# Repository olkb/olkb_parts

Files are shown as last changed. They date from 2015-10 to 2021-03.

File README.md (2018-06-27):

# OLKB Design Files

These are the source files for the hardware made (currently and previously) by [OLKB](https://olkb.com).

> These works are licensed under the Creative Commons Attribution-ShareAlike 4.0 International License. To view a copy of this license, visit http://creativecommons.org/licenses/by-sa/4.0/ or send a letter to Creative Commons, PO Box 1866, Mountain View, CA 94042, USA.

This means you can run Group Buys of these designs, as long as you credit where the design came from (this repo).

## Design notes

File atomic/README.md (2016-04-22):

# The Atomic Keyboard

## Tops

* TOPASK50: Short space
* TOPAUN50: Universal MX
* TOPJAS50: Semi-grid
* TOPJCK50: Semi-standard
* TOPKLN50: Full-grid
* TOPMAU50: Universal Matias
* TOPMLO50: Alt short space

## Middles

* MIDATM50: Middle piece with stabiliser and usb cut-out

## Bottoms

* BOTATM50-MSH: Milled bottom
* BOTATM50: Plate bottom

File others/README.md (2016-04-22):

# Other keyboard designs

* BOTNEU50: Neutrino bottom plate
* MIDMOL50: Neutrino middle piece
* TOPNEU50: Neutrino top plate
* TOPQUA50: Quark top plate

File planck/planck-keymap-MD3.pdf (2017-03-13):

### Main typing layers (Qwerty, Lower, Raise)

# Planck default keymap - QMK Firmware

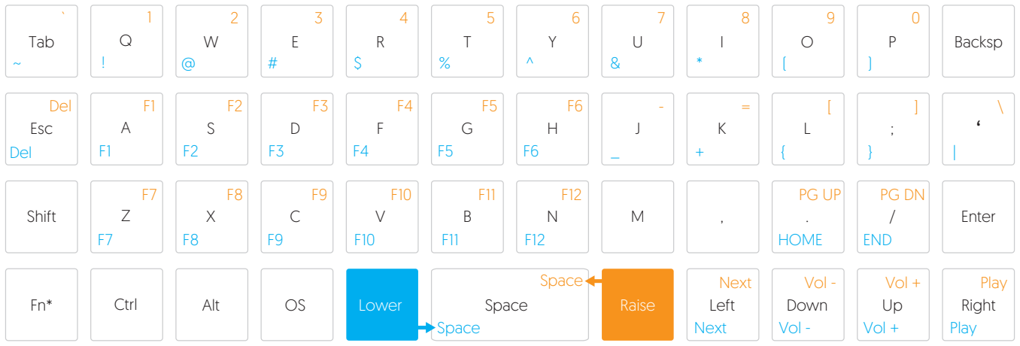
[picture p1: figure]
Tab; Backsp; Del; HOME; END; Next; Vol -; Vol +; Play; ‘ Esc; Shift; Enter; Ctrl; Alt; Lower; Space; Raise; Left; Down; Right

### Adjust layer (Lower + Raise together)

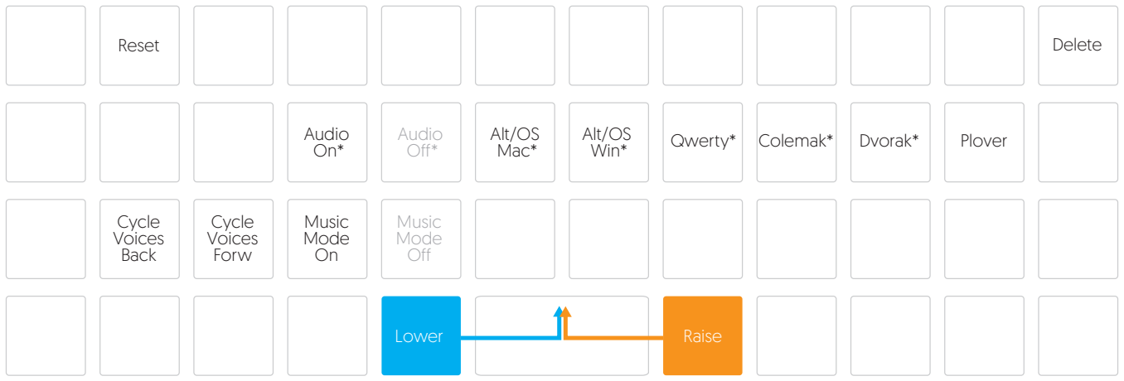
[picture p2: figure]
Reset; Music Mode On; Cycle Voices Forw; Cycle Voices Back; Audio On*; Alt/OS; Mac*; Qwerty* Colemak* Dvorak*; Plover; Delete; Alt/OS Win*; Audio Off*; Music Mode Off; Lower; Raise

* These options are persistant over keyboard power loss and stored in the EEPROM (you’ll only need to set them once)

* Fn presses shift and cycles through the backlight settings

For more information on the firmware, visit https://github.com/qmk/qmk_firmware. The default keymap evolves over time, and the one in the repo may be slightly different than what is shown here - for the Massdrop that started in March 2017, this is the keymap that came programmed onto the PCBs, and can be used as a typing reference.

Many keys on the Lower/Raise layers were left blank for customising, so consider adjusting things to your liking! Compiling instructions are on the repo’s wiki.

## OLKB.COM

keyboard store

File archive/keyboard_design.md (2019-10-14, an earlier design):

Terminology

FROM SWITCH CENTER (FSC)

When discussing the spacings around the edge of the plate, the terminology "from switch center" (FSC) will be used. In that sense, the MX switch cutouts themselves are 7mm FSC, or 14mm x 14mm. The standard plate designs for OLKB are all 12mm FSC - this means the plates come out 2.5mm from the edge of the keycaps. Some 9.5mm FSC plates/cases are also being planned.

GRID SPACING (GS)

The Planck, Atomic, and Matias boards use a 19mm grid spacing (GS), meaning there is 19mm between the switch centers for two normal, 1 unit keys - with this, 1u (unit) can be defined as 19mm. Other common boards (Cherry, etc) have a 19.05mm GS.

View All OLKB parts on github

PLANCK

The 12mm FSC plates are 233mm x 81mm in size and 1.54mm thick (16 gauge stainless steel), with 2.5mm (previously 3mm) diameter mounting holes in the following locations (distances from top left corner when looking down) (x, y):

(21.5mm, 21.5mm)

(211.5mm, 21.5mm)

(116.5mm, 40.5mm)

(21.5mm, 59.5mm)

(211.5mm, 59.5mm)

The PCB was designed to fit into the milled cases - the walls of which start at 8.9mm FSC, and are 3.1mm thick. The inside corner radius of the walls is 6.35mm - this makes the case cheaper to produce, and comes right to the edge of the keyswitches.

3D PRINT YOUR OWN PLANCK PARTS!

View all of the parts on github. (Atomic and other parts are available too)

Adam Forland has kindly proto-printed the Planck bottom using the plans I made for the Planck milled bottom. This 6-piece design turns out slightly better due to ABS's tendency to warp, and can be easily glued together.

The Planck bottom has 1.6mm diameter holes, which are ready to tap with a 2mm/M2 tap for the assembly kits I sell.

The Planck middle piece is designed for use with the regular bottom plate (and top plate), and shares the same side clearances as the bottom piece.

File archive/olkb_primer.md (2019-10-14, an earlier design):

Mechanical keyboards can be a little overwhelming when seeing all of the different options! This page will serve as a brief guide on what you might be buying from OLKB or other stores. Feel free to suggest additional links/info!

## Guides to check out

* [OLKB PCB assembly guide](http://olkb.com/help/guide)
* [Quantum firmware documentation (up-to-date)](https://docs.qmk.fm)
* [How to hand-wire a keyboard](http://deskthority.net/workshop-f7/brownfox-step-by-step-t6050.html)

## The term "ortholinear"

Ortholinear is a semi-made-up word that was originally coined (to my knowledge) by [TypeMatrix](http://www.typematrix.com/study/) as "ortho-linear" - this term got concatenated, became popular among the keyboard community, and eventually became the banner for a keyboard company!

It refers to keyboard layouts where the keys are aligned vertically and horizontally, compared to standard staggered keyboards. No studies have been done to test the ergonomics of ortholinear keyboards (versus a comparable staggered one), but the change can make it easier to design and visual custom keymaps, and may help relieve RSI symptoms.

## Construction

The keyboards sold on OLKB generally have a top and a bottom (and sometimes a middle) - the switches fit into holes in the top plate, and then are either hand-wired to a Teensy 2.0 (or other microcontroller) or a PCB. In practice, it's much easier to place the switches one-by-one into the plate *and* PCB than it is to place all switches into the plate, *then* the PCB.

10mm between the top and bottom plates is usually enough room to fit all of the necessary components for a PCB or hand-wired build. Additional M2 brass spacer sizes [can be found on Amazon](http://www.amazon.com/s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).

## Switch Types

There are a lot of different types of modern switches, but they can be separately into two categories that are available for these/custom keyboards:

* MX-compatible switches
  * Cherry MX
  * Gateron
  * Kailh
  * Greetech
* Matias-compatible switches
  * Matias
  * ALPS XM

Each has variations that will affect the feeling/sound of the switch, and are usually denoted by colors. [More information on the various types can be found here](https://www.reddit.com/r/MechanicalKeyboards/wiki/switch_guides).

## OLKB Keyboards

I'm always thinking about new keyboards to make, but these are the OLKB keyboards that have been announced/are for sale currently:

* [Planck](/planck) - a 40% (4u x 12u) keyboard
* [Preonic](/preonic) - a 50% (5u x 12u) keyboard

## Firmware

The PCBs and the Teensy 2.0 use Atmel's Atmega32u4 AVR controller, so all firmware is compatible with both. [The official firmware](https://github.com/qmk/qmk_firmware/) for OLKB boards is called Quantum, and is based on the [TMK Keyboard firmware](https://github.com/tmk/tmk_keyboard/). Quantum contains a lot of helpful shortcuts to make building your custom keyboard/layout easier.

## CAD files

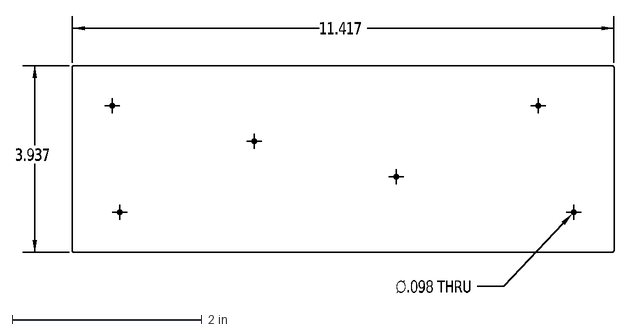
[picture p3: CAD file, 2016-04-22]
atomic/bottoms/BOTATM50.dxf
11.417
3.937
∅.098 THRU

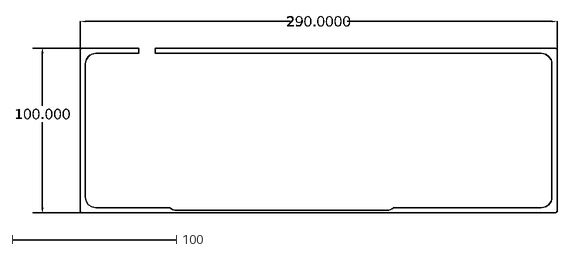
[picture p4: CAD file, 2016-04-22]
atomic/middles/MIDATM50.dxf
100.000
290.0000

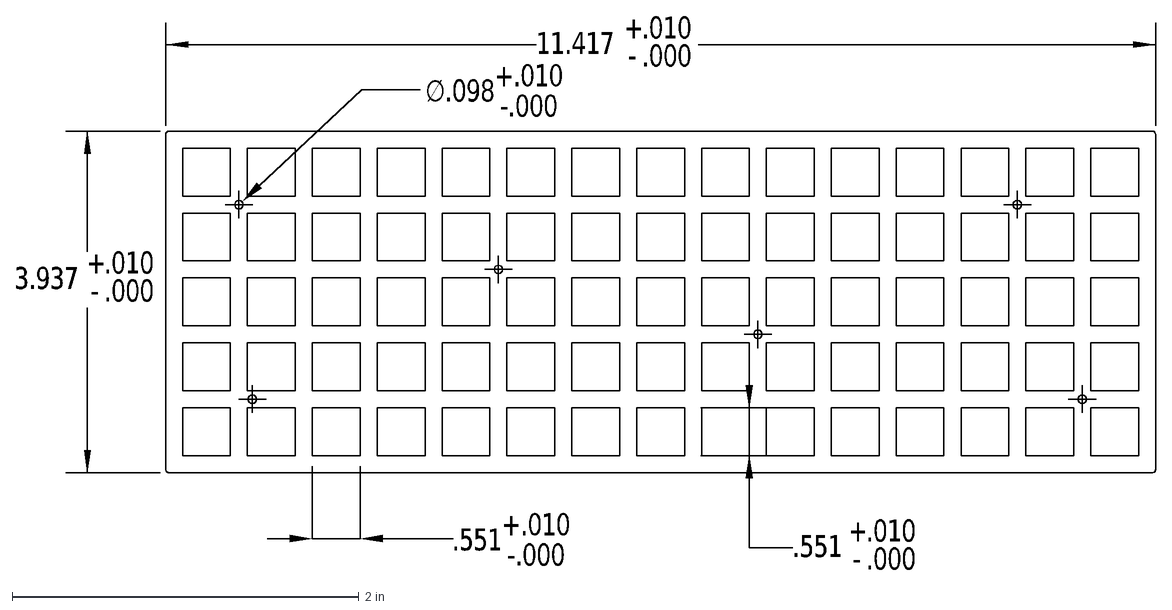
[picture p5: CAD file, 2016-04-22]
atomic/tops/TOPKLN50.dxf
11.417
+
-
.010
.000
3.937
.551+.010^-.000
.551
∅.098+.010^-.000

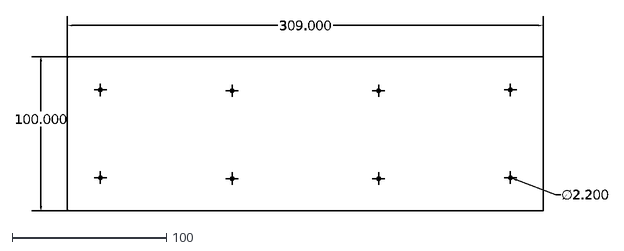
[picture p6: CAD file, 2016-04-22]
others/BOTNEU50.dxf
309.000
100.000
∅2.200

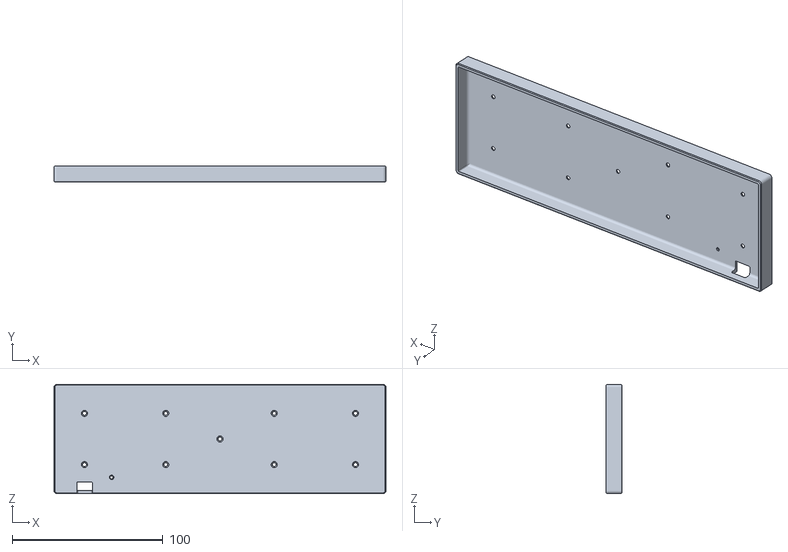
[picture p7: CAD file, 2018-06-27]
planck/light/light-bottom.stl
220.5 x 10.5 x 72.5

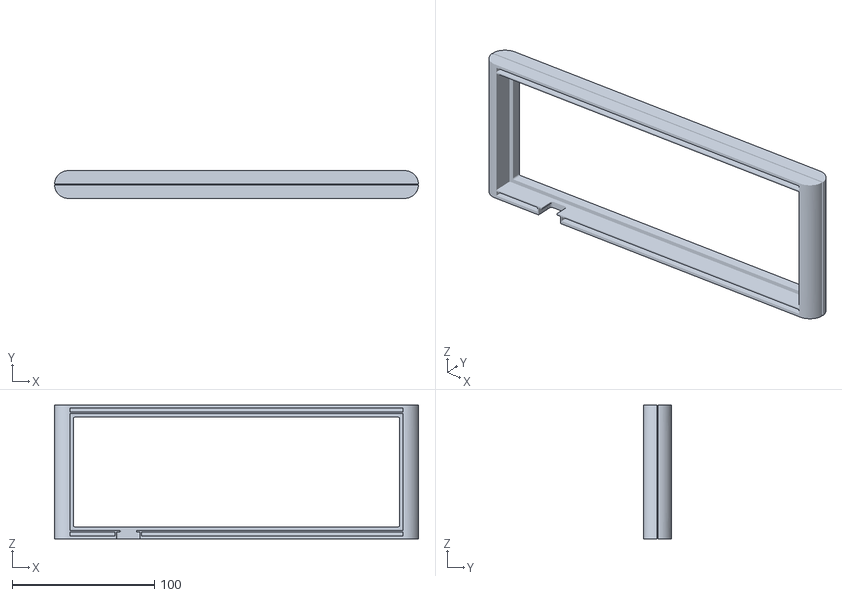
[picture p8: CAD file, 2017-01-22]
planck/lo-pro-covers/case-cover-atari.stl
255.5 x 19.5 x 94.0

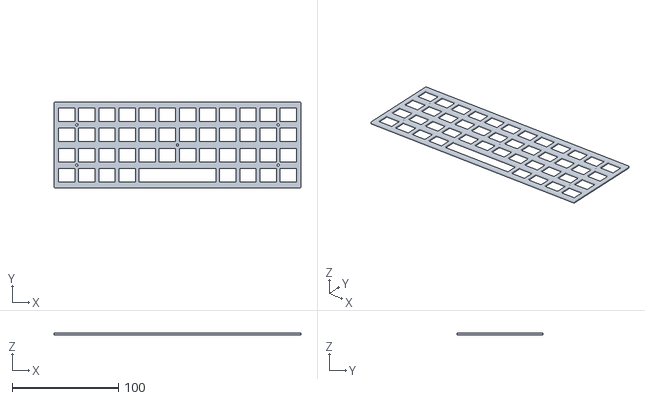
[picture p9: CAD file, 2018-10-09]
planck/lo-pro-plate-matias-2x2u.stl
233.0 x 81.0 x 1.54

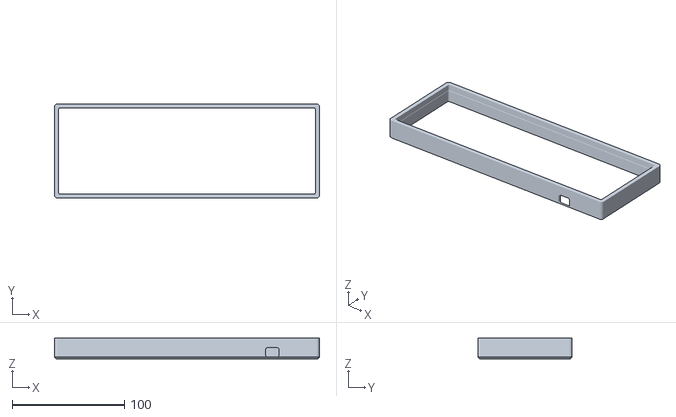
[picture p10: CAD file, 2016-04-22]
planck/middles/MIDPLK50-MSH-COVER.stl
236.0 x 84.0 x 18.5

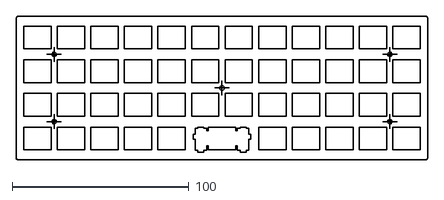
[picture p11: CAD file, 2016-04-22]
planck/tops/TOPMIT50-MTS.dxf
233.0 x 81.0

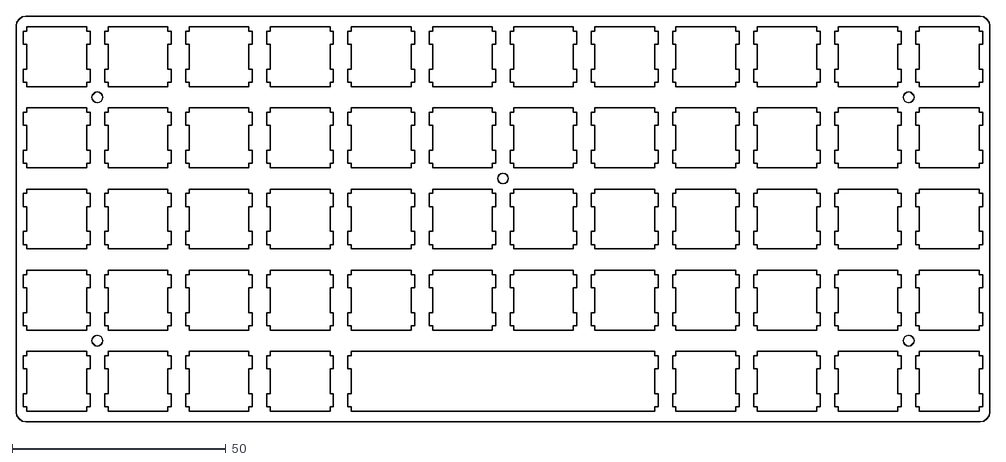
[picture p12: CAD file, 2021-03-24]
preonic/preonic-plate.dxf
228.0 x 95.0

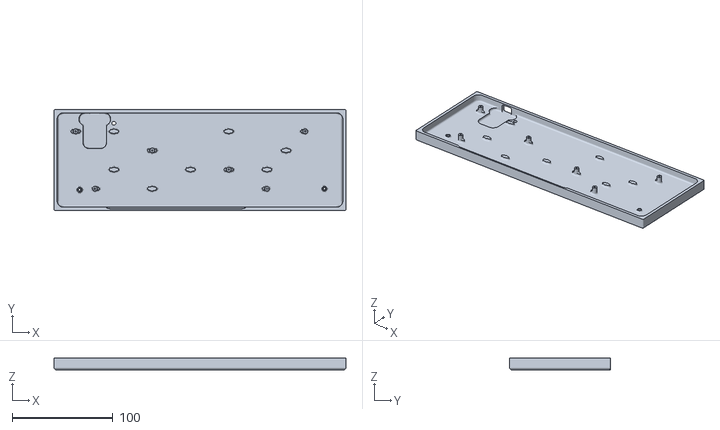
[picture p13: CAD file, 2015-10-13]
atomic/bottoms/BOTATM50-MSH.stl
290.0 x 100.0 x 11.5

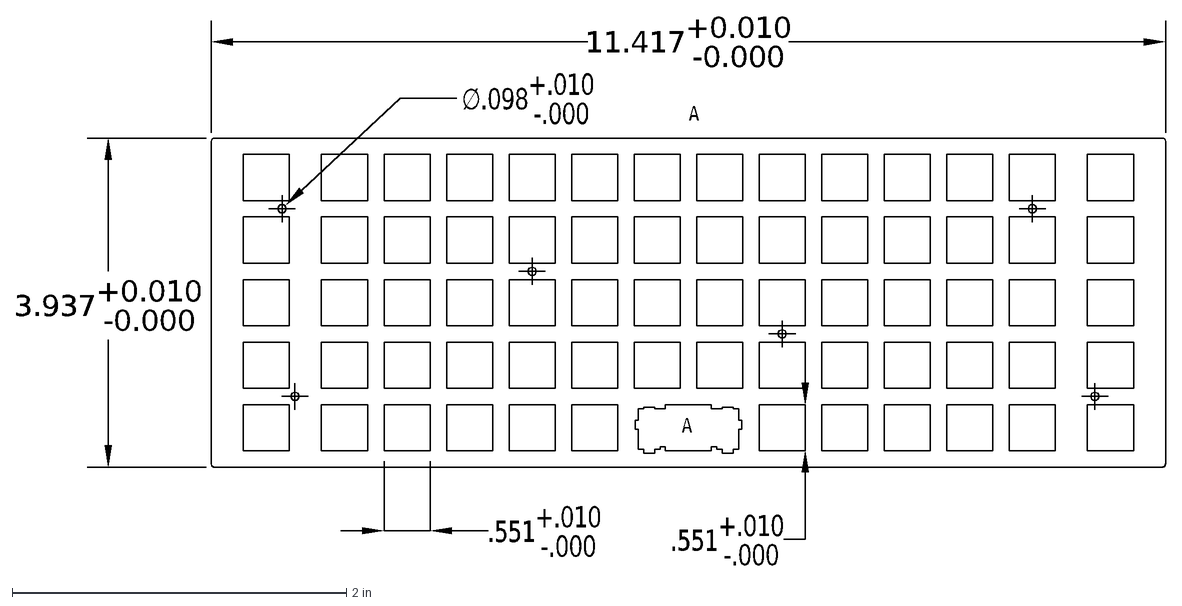
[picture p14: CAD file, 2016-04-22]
atomic/tops/TOPJAS50.dxf
.551+.010^-.000
∅.098+.010^-.000
A
11.417+0.010^-0.000
3.937+0.010^-0.000

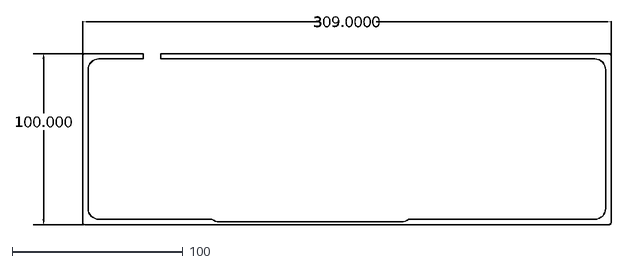
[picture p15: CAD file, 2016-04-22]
others/MIDMOL50.dxf
100.000
309.0000

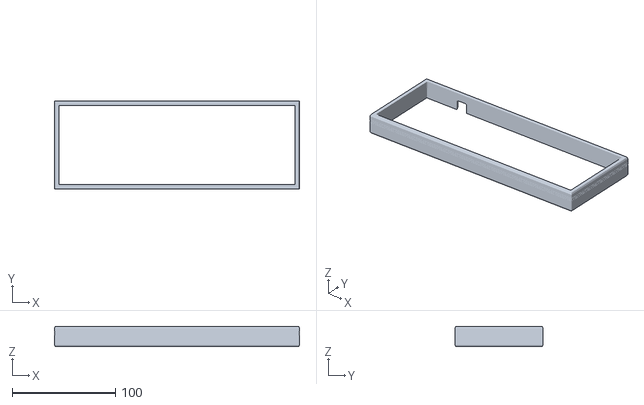
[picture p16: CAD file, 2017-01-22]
planck/lo-pro-covers/case-cover-90s.stl
237.5 x 85.5 x 19.5

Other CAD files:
planck/lo-pro-plate-mx-2x2u.stl
planck/middles/MIDPLK50-12.stl
planck/tops/TOPGRD50.dxf
preonic/preonic-rev3-hipro-mod.stl
atomic/tops/TOPASK50.dxf
atomic/tops/TOPAUN50.dxf
atomic/tops/TOPJCK50.dxf
atomic/tops/TOPMAU50.dxf
atomic/tops/TOPMLO50.dxf
others/TOPNEU50.dxf
others/TOPQUA50.dxf
planck/bottom-plate.dxf
planck/hi-pro-bottom-mod.stl
planck/hi-pro-bottom.stl
planck/hi-pro-plate-matias-2x2u.stl
planck/hi-pro-plate-matias.stl
planck/hi-pro-plate-mx-2x2u.stl
planck/hi-pro-plate-mx.stl
planck/lo-pro-bottom.stl
planck/lo-pro-covers/case-cover-high.stl
planck/lo-pro-covers/case-cover-plain.stl
planck/middles/MIDPLK50-10.stl
planck/middles/MIDPLK50-14.stl
planck/old/TOPGRD50.dxf
planck/old/TOPMIT50.dxf
planck/old/TOPPMU50.dxf
planck/old/TOPPUN50.dxf
planck/old/middles/MIDPLK50-10.stl
planck/old/middles/MIDPLK50-12.stl
planck/old/middles/MIDPLK50-14.stl
planck/tops/TOPMIT50.dxf
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

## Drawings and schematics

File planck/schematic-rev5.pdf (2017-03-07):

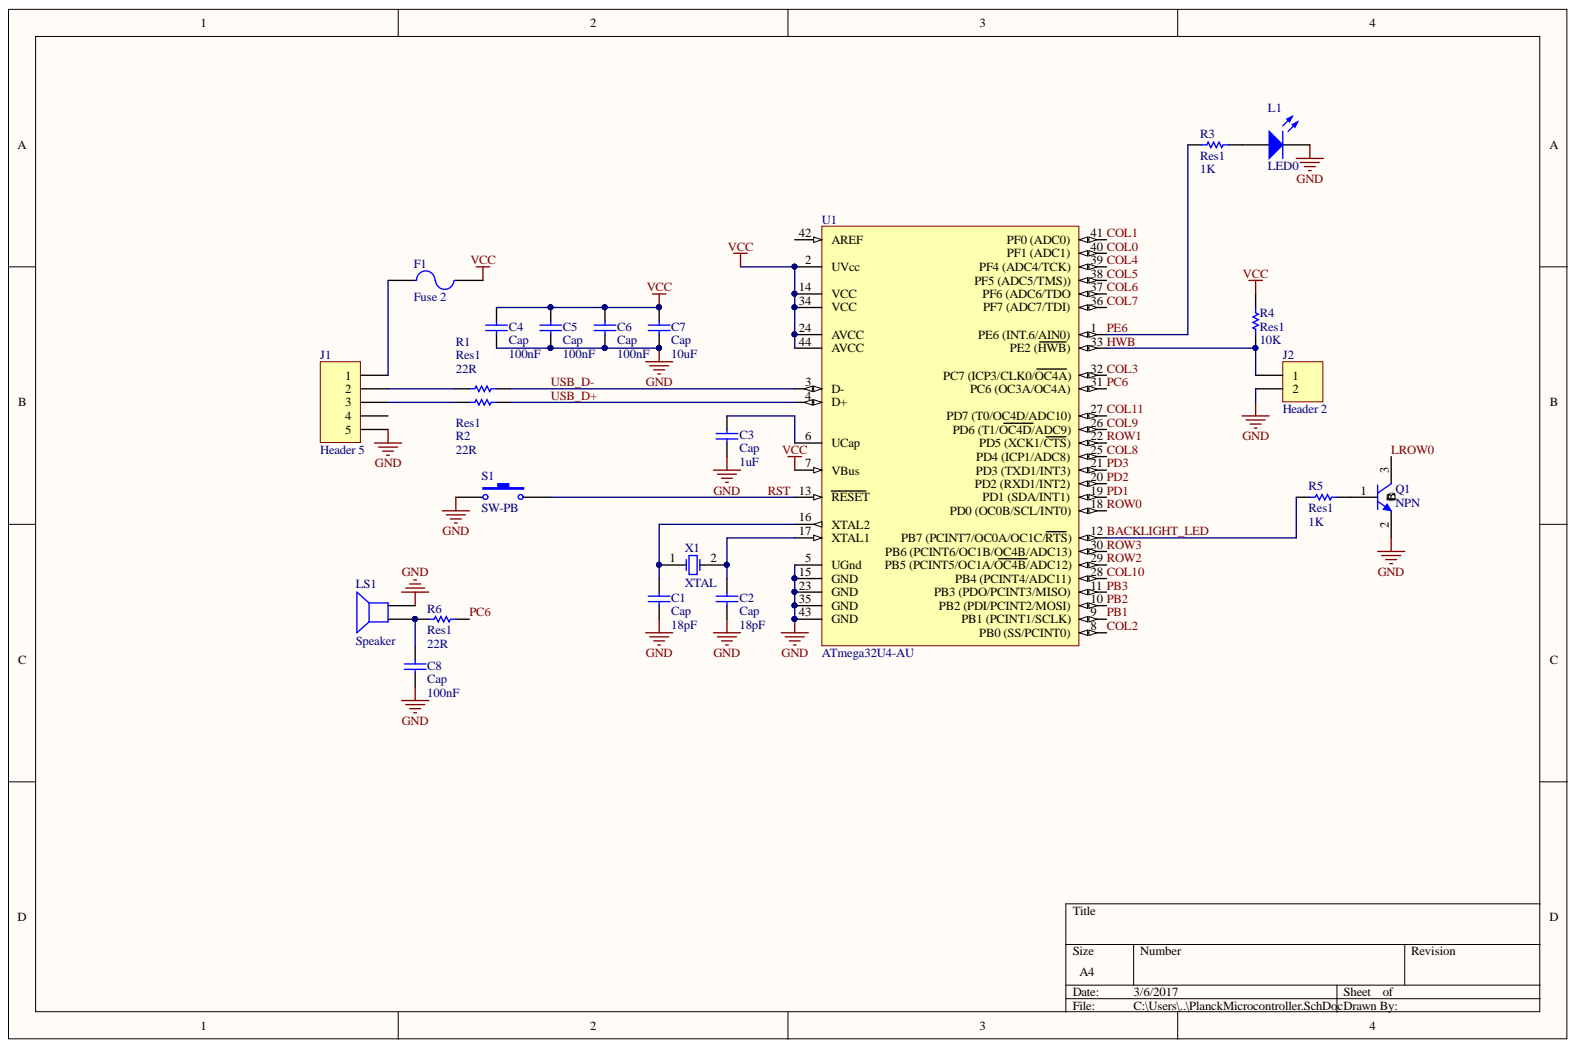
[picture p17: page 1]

D+ 4 D- 3 | COL3

UCap 6

VCC RST | VBus 7

ROW0 BACKLIGHT_LED

UGnd 5

GND 23

Size A4 | Number | Revision

Date: 3/6/2017 | Sheet of
File: C:\Users\..\PlanckMicrocontroller.SchDocDrawn By:

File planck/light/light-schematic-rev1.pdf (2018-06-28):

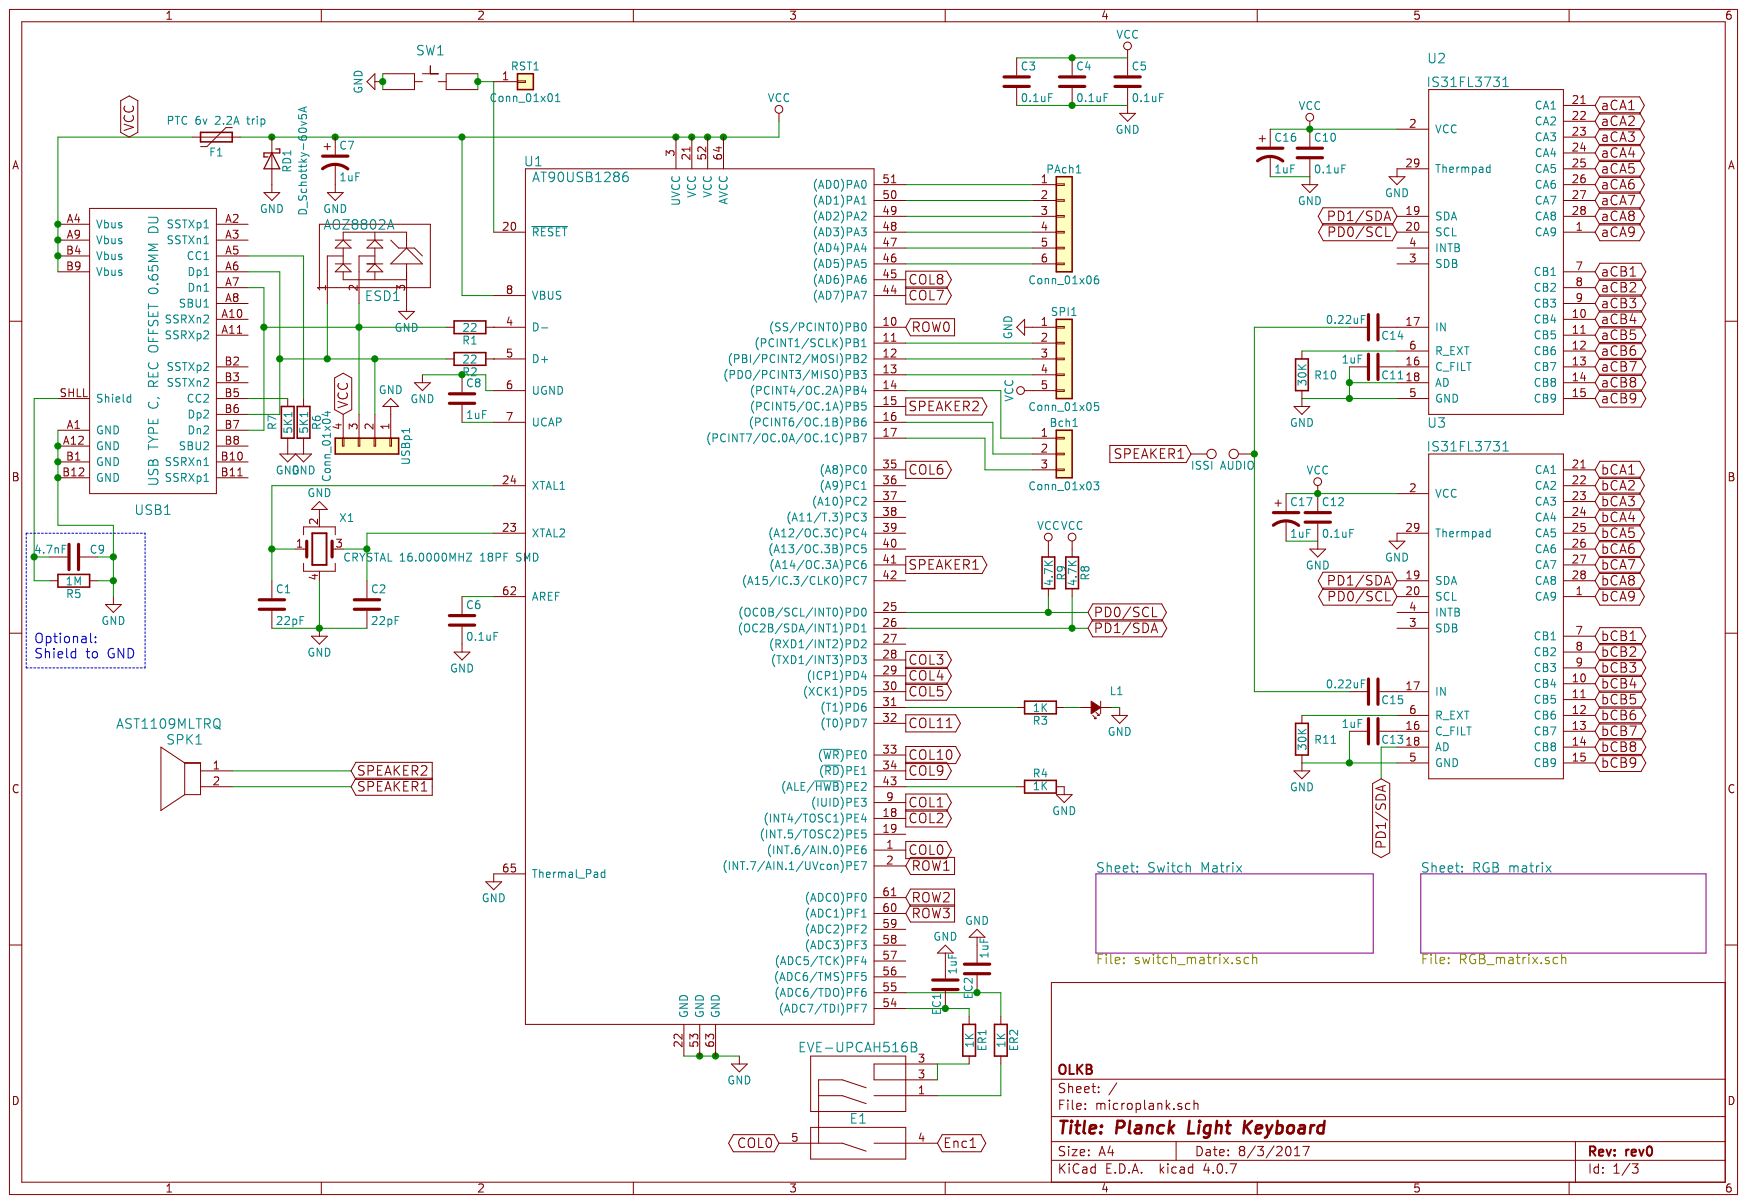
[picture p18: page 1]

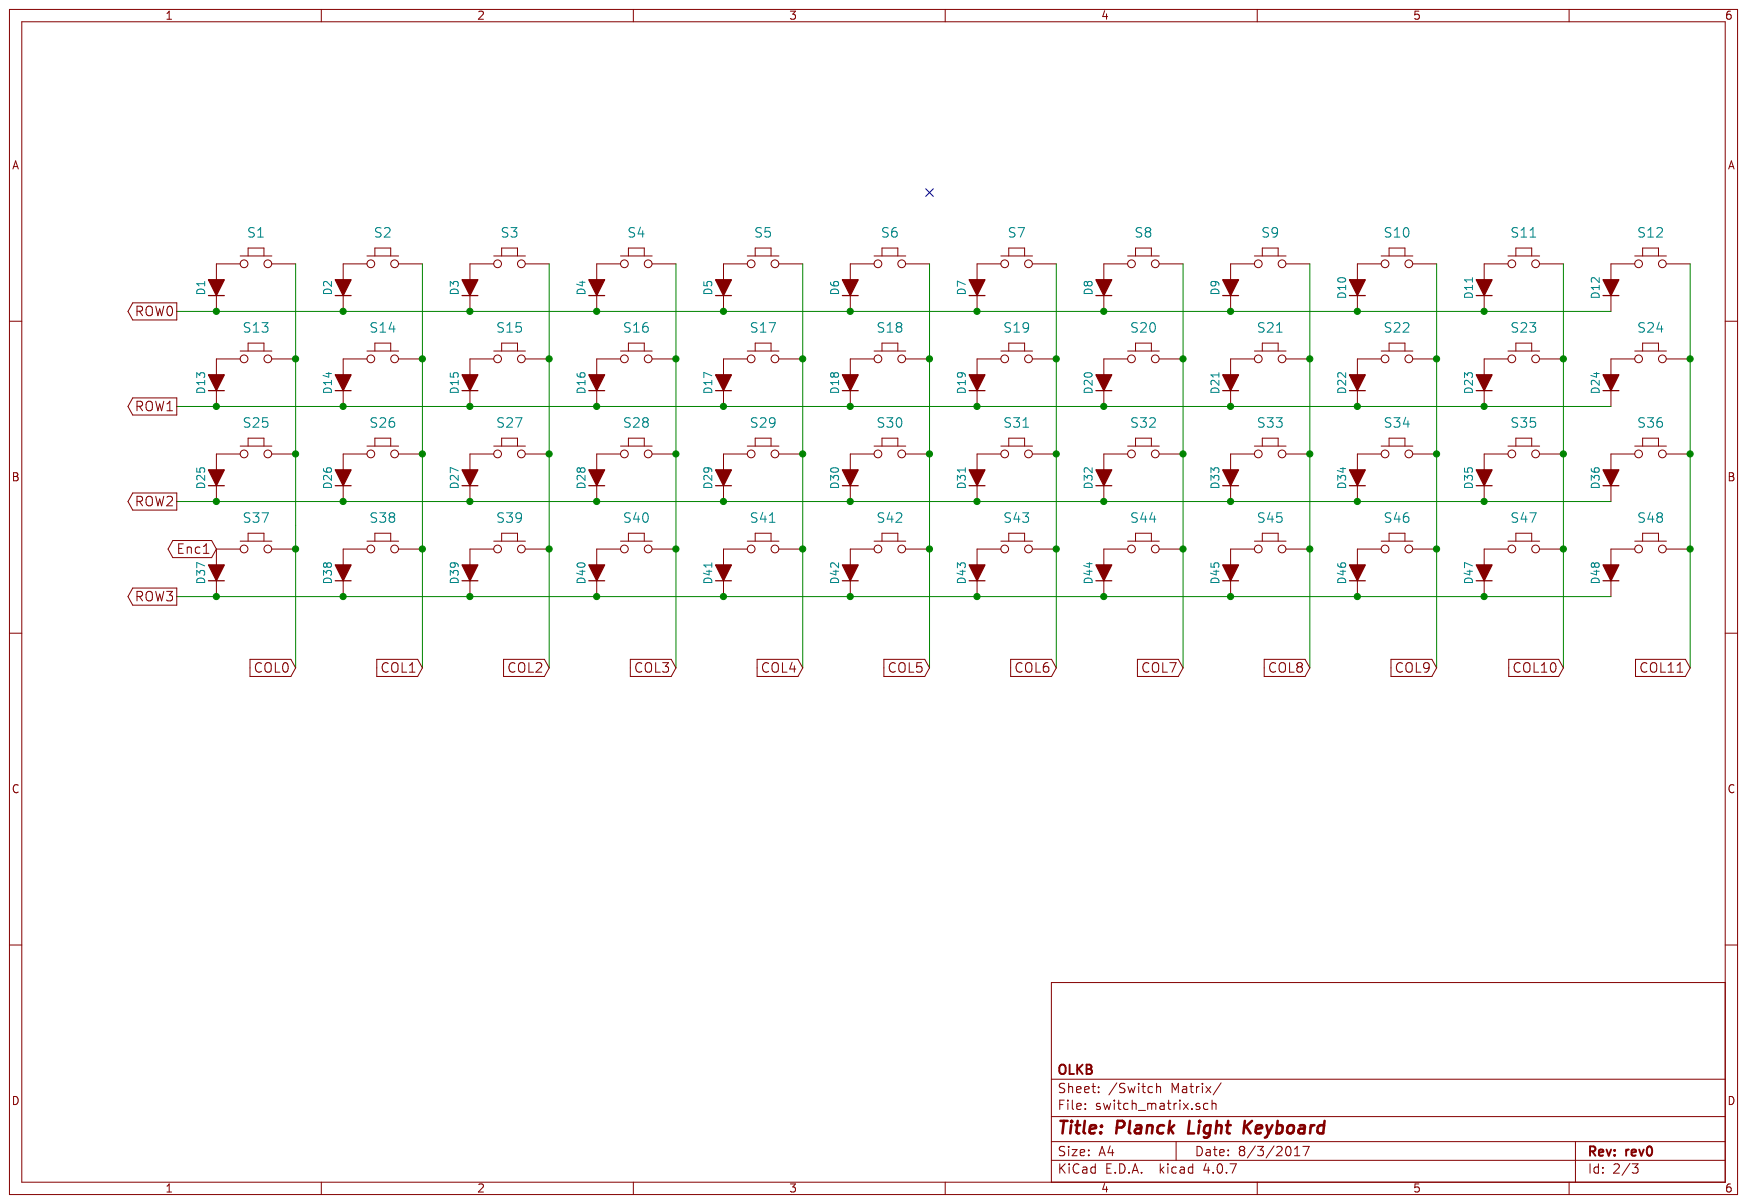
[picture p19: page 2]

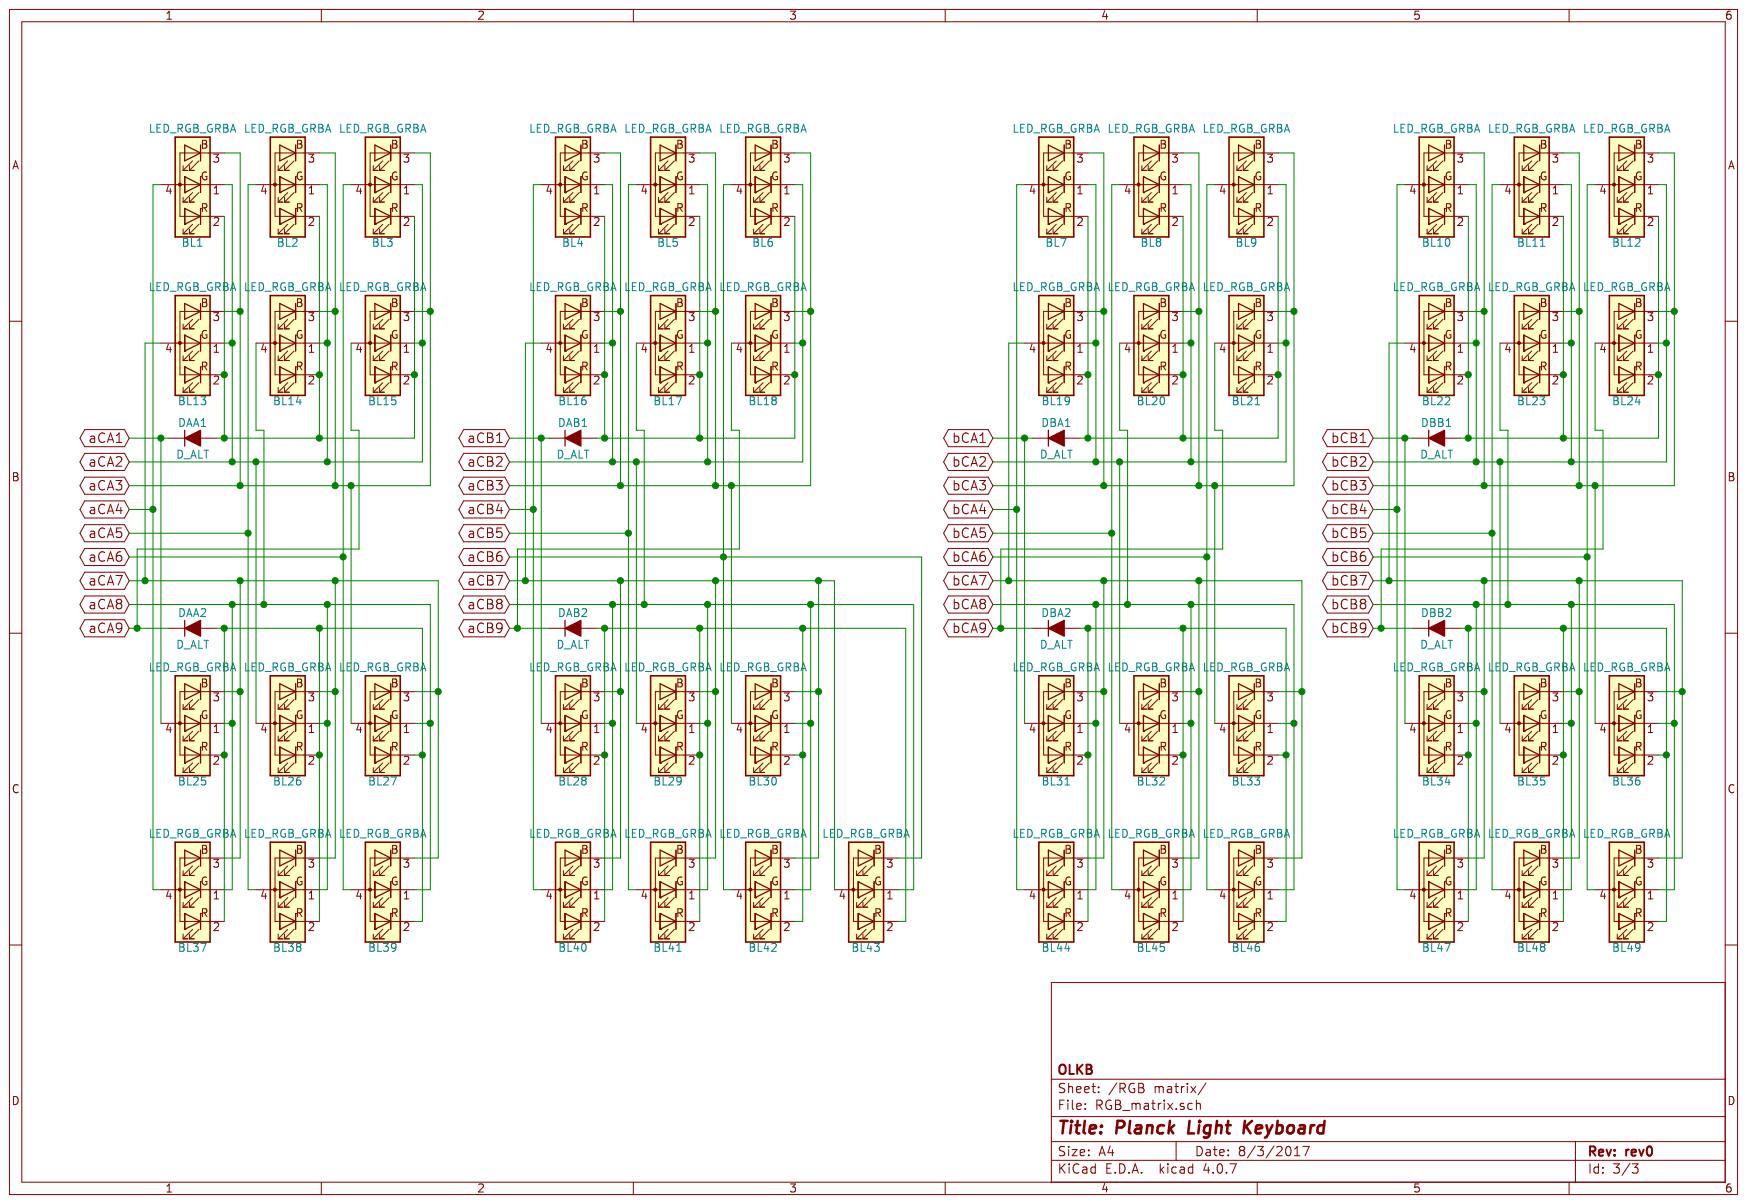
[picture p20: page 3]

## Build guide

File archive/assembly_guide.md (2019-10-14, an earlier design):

ASSEMBLY GUIDE

PREPARATION

The PCB comes pre-programmed with the standard layout that can be seen here. To make sure the PCB is (still) functional, plugging it into a computer should result in the green LED being lit-up. If it doesn't, you may need to make sure your computer is treating it as an actual keyboard (let it install drivers/click confirmation boxes) and giving it power. This shouldn't be a problem for most machines.

OPTIONAL SIP INSTALLATION

If you've opted to place SIPs in your keyswitches, and you're using a closed plate (non-universal, like the MIT plate), now is the time to do so! If you're using an open plate (universal) or none at all, these can be installed anytime afterwards.

Remove the top of each keyswitch by allowing the 4 "claws" to pass over the bottom half's lips. It's much easier to place the SIP while holding the switch top slightly above the bottom, keeping the spring and internal mechanism aligned with each other. Once the SIP is in place, you can carefully place the top back on.

ASSEMBLY

Once you've ensured that the glowy bits are glowing correctly, you can get started on assembly! Placing a few keyswitches into the plate (if you're using one) and then pushing the PCB (the nearly blank side) onto those few is the preferred method to seat the PCB against the keyswitches correctly. Putting all of the switches in the plate, then pushing the PCB onto all of them is very difficult, and can lead to errors with the pins.

Once you have a few switches in (start with the corners) and the PCB attached, you can carefully place the half-assembled unit into your case (if you have one) to finish placing the switches. Inspect each switch with a quick clicky-clicky and make sure the pins are sticking out straight - it's semi-difficult to remove the switches after placing them.

When done placing the switches, remove the keyboard from the case and inspect the pins sticking out from the board - you should be able to feel/see all of them sticking out the same distance. If the distance varies at all, it may be an indication that the PCB isn't seated correctly. Pressing carefully but firmly on the PCB/switch (watch out for components) should help it to travel as far as it can - you may hear a satisfying click once it's in place.

LED INSTALLATION

If you plan to install 3mm LEDs (without SIPs), now is the time to do so! Looking at the bottom of the PCB (the labelled side), you should be able to see a + or - by every LED pad. As a reminder, the longer end of the LED needs to be aligned to the + side. Pay attention as the orientation varies a lot on the bottom row.

If you're using SIPs, you won't need to place the LEDs now - that can be done once the board is complete. Be sure to be mindful of their orientation when installing them, though.

You'll always be able to install LEDs later on - there's nothing preventing you from doing that in the future.

SOLDERING

If all of the pins are sticking through the board, you're ready to start soldering! Make sure your soldering iron is hot and you have some good ventilation. Turning on an adjacent fan is recommended so you're not inhaling/exposing yourself to the solder fumes.

When soldering each pin, it's best to place the tip of the iron on the pin/pad and push the solder into the intersection of the two. Getting them hot helps the solder to form a good connection. Try not to get solder anywhere but on the gold pad, and be sure not to form any bridges with nearby components. Doing so may cause random key presses or break things (temporarily, likely).

The size of the solder you're using is mostly unimportant, but it's recommended that you use a smaller gauge (smaller in diameter), as it will be easier to control the flow. It is recommended that the solder be rosin/flux cored to help it flow onto the pads. Additional flux may be used, but shouldn't be needed.

You'll be soldering 2 pins for each keyswitch, and 2 pins on the LEDs/SIPs, if you're installing those.

INSPECTION

Once you have all of the pins soldered, you'll want to inspect each of them to make sure the solder has correctly tented over the pad. The PCB is not prone to many errors (unlike hand-wired builds), but they can happen.

If you're sure everything looks good, place the keyboard into its case, and plug it in. Pressing on a keyswitch should result in some action, so open up a text editor to type into. Pick a switch in the middle of the keyboard to make sure it'll be a letter, and not something unexpected. If it looks like you're getting something, go ahead and test every switch to make sure each has a good connection. Some switches may be modifiers or the LED control.

To test the LEDs, press the key in the lower left-hand corner until the LEDs light up. Pressing the button cycles through the various levels in the firmware (0-4) - it may take a couple of presses to be able to see the light.

FINISHING-UP

If all is working, screw in the screws to your case, and close it up! If you're using the milled bottom, you'll be able to reset the board for flashing with a paperclip after everything is sealed up. If you're not, you may want to hold-off on closing things up until you've successfully programmed it.

Once screwed into place, stick some keycaps on that thing, and call it done! The screws can be difficult to place once the keycaps are on.

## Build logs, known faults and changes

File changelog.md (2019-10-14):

# OLKB Part Changelog

## Planck PCBs

* rev 1
* rev 2
  * breakout various pins
* rev 3
  * larger holes for Zealio switches
* rev 4
  * speaker added to C6
* rev 5
  * mounting holes increased from 2.2mm to 2.85mm for Hi-Pro/EOTW cases
* rev 6
  * Complete redesign, upgrade to Arm
  * USB Type-C
  * 2x2u support
  * No in-switch LEDs
  * Speaker tied to two outputs
  * Many footprints for addons
* rev 6.1
  * USB-C to USB-C bi-directionality fixed
  * Sturdier 2u stabiliser holes
  
## Preonic PCBs

* rev 1
* rev 2
  * mounting holes increased from 2.2mm to 2.85mm for Hi-Pro/EOTW cases
* rev 3
  * Complete redesign, upgrade to Arm
  * USB Type-C
  * 2x2u support
  * No in-switch LEDs
  * Speaker tied to two outputs
  * Many footprints for addons

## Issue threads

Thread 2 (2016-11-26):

Dimensions seems to be wrong

xobtoor, 2016-11-26:
Something with the dimensions seems wrong or i'm making some mistakes.

This is visible in multiple Programms like Fusion360, slic3r, inkscape, and cura

Examples:
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

Only the bottom part seems right.
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

jackhumbert, 2016-11-26:
Thanks, yeah - I broke the cardinal rule and scaled the drawing :/ Planck tops plates should be scaled to 233mm on their largest dimension. I'll get them fixed here later today.

jpotier, 2017-09-16:
Hey, atomic dxf's seem to display the same problem. I have a spare top plate and would like to have the other parts printed, but the dimensions are wrong. Could you give it a quick update too?

Closed 2020-10-12.

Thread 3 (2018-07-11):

Uploading 3D CAD Files

ChasingAir, 2018-07-11:
Is there any way you could upload .stp/.step, .sat, or .prt files? I'm specifically looking for the hi-pro-bottom. Thanks!

ChasingAir, 2019-04-29:
@jackhumbert Is there any hope for this issue? I know you're busy and I'm not trying to be pushy, I'm just curious, thanks!

The-Bob, 2019-09-15:
+1

ftlno, 2020-11-12:
+1 would love .stp files @jackhumbert ! :D

hanhanhan-kim, 2021-03-31:
Hello! I would also be very interested in the actual solid files (`.step` would be great!)

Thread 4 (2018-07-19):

lo-pro mx plate

anthonyrichir, 2018-07-19:
Hi,

I don't see the stl for the lo-pro plate for MX switches, is it available ?
I just ordered a Planck via Massdrop but didn't received the plate and I'm not getting answer from the support, I thought I could build one myself if I find someone to produce it from the stl.

Thanks in advance

KTSCode, 2018-08-08:
I would also like an stl for the lo-pro plate for MX switches

anthonyrichir, 2018-09-05:
Any chance to get an answer @jackhumbert ?

ChasingAir, 2018-10-05:
I would also really like this!

jackhumbert, 2018-10-09:
[Just uploaded this!](https://github.com/olkb/olkb_parts/blob/master/planck/lo-pro-plate-mx-2x2u.stl) :)

anthonyrichir, 2018-10-09:
Nice ! Thank you very much !

Closed 2018-10-09.

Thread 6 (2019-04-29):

Lo-Pro Case Seems Wrong

ChasingAir, 2019-04-29:
The "lo-pro-bottom.stl" seems to be an old version and not match the current design. Could you upload the new version? Also, if you had a .step or .sat file, that would be wicked!!!

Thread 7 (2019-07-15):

Preonic Rev3 Hi-Pro Mod Case Bottom STL

equalunique, 2019-07-15:
Hi,

I noticed that while the other case files are found in olkb_parts/preonic, the file for the mod case is missing. Can this please be added?

Thanks!

equalunique, 2019-10-06:
Would really appreciate it this could be added since I have some other 3D printed parts and would *love* a Preonic case in matching filament.

boboysdadda, 2019-12-28:
I'd like to 2nd this. Saw the run for the mod kit on Massdrop and it looks like it only ran that 1 time.
https://drop.com/buy/massdrop-x-olkb-preonic-utility-kit

Anyone else who would like to do it will likely have to source the parts on their own. The case being the hardest part. Please make this available to us if possible.

Thanks again for such and awesome keeb

jackhumbert, 2019-12-29:
Uploaded :) https://github.com/olkb/olkb_parts/blob/master/preonic/preonic-rev3-hipro-mod.stl

Closed 2019-12-29.

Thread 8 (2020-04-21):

Planck rev6 schematics missing?

kaspar030, 2020-04-21:

stephan-jacobs, 2022-07-24:
Given that a lot of Planck Rev 6 PCBs have issues it'd be incredibly helpful to have access to these. Please and thank you!

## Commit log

2015-03-30 addin' stuff
    [BOTPLK50-MSH.stl]
2015-04-01 other heights
    [MIDPLK50-10.stl, MIDPLK50-12.stl, MIDPLK50-14.stl]
2015-10-13 atomic milled bottom
    [BOTATM50-MSH.stl]
2016-04-22 adds atomic, planck, other designs and folders
    [BOTATM50-MSH.stl, BOTATM50.dxf, BOTNEU50.dxf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]
2016-04-22 adds readmes and license
    [TOPHAR50.dxf]
2017-01-22 added case covers
    [case-cover-90s.stl, case-cover-atari.stl, case-cover-plain.stl]
2017-03-07 adds Planck schematic
2018-06-27 reorg, add current files
    [MIDPLK50-10.stl, MIDPLK50-12.stl, MIDPLK50-14.stl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]
2018-06-28 adds planck light schematic
2018-10-09 add planck pcb module
2018-10-09 add lo-pro mx planck
    [lo-pro-plate-mx-2x2u.stl]
2018-10-09 add lo-pro ma plate
    [lo-pro-plate-ma-2x2u.stl]
2018-10-09 rename matias plate
    [lo-pro-plate-matias-2x2u.stl]
2019-11-19 add preonic sidse
    [PRE-END.stl]
